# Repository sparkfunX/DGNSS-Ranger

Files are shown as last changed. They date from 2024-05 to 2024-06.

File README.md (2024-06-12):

# DGNSS_Ranger
Shoulder-Mounted Collapsable LIDAR-DGNSS Rangefinder/Locator Development Platform

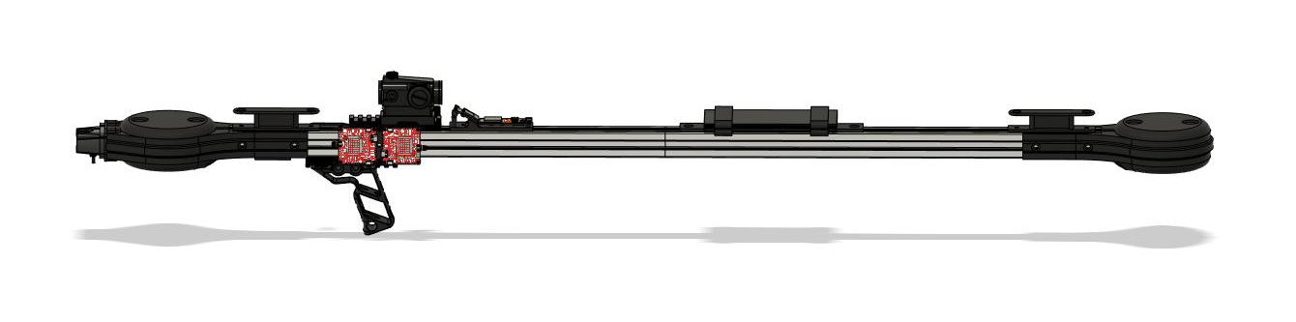
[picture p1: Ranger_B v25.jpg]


## Theory of Operation 
By using two GNSS receivers operating in RTK with corrections data from a fixed base (or comparable corrections source) the relative position of two antennas can be determined. This relative position can be used to derive a heading without the use of a magnetic compass. Furthermore, by placing a ranging sensor (in this case, a LIDAR) in line with these antennas, it's possible to derive the Geodetic coordinates of a subject at distance. This is acheived by virtually extending a line that connects the two antennas by the distance reported by the LIDAR. This may be useful in applications such as surveying, geotagging, structural measurments, etc. where it's neccessary to retrieve the coordinates of an inaccessible subject. The shoulder-mounted form factor of this platform makes it easier to use and transport than many traditional surveying tools, at the expense of some positional accuracy. 

## Sources of Error
We've determined the theoretical maximum 3D positional error of the platform at full distance (40 meters) to be 0.85 meters. This error is the result of compounding error from various sources.

#### GNSS Error
The maximum 3D accuracy of the ZED-F9P with a clear view of the sky and adequate corrections data is 0.02 meters. This error is inherent to the method and can't be technically addressed by this project.

#### Differential Error at Distance 
Assuming the maximum 3D positional error of the forward antenna is 0.02m, and that its distance from the rear antenna is 0.95m, we derive an angular error of 1.206° (The α angle of the right triangle with b side 0.95 and a side 0.02) such that at 40 meters, the maximum positional error becomes 0.85 meters (The a side of the right triangle with α angle 1.206° and b side 40). This error can be reduced by increasing the length of the platform and, therefore, the distance between the two GNSS antennas. This is because the angular error is reduced with an increased distance given the same positional error (Observe the difference in angle between a right triangle with b side 0.95 and a side 0.02 and another right triangle with b side 2 and a side 0.02). The distance between the two antenna does not need to be calibrated, as it is measured using DGNSS, and so it is possible to extend the platform's length as much as is practical in a given application without modifying the firmware. This error also shrinks with the distance to the subject and so more accurate coordinates are derived from nearer subjects. Note: The inter-antenna distance is automatically derived via DGNSS, but the distance between the LIDAR unit and the forward antenna ARP should remain fixed and must be accounted for in the firmware configuration. 

#### LIDAR Ranging Error
The accuracy of any LIDAR rangefinder will depend on a number of environmental factors, including the cross-sectional area and reflectivity of the subject to be measured. For this reason, ranging errors are not included in our maximum error figure. 

## Electrical Assembly
Almost all of the electronics on the platform are SparkFun Qwiic development boards and can be connected using Qwiic cables in whatever order is most mechanically convenient. The only exceptions are the trigger button and the LIDAR-lite module. The trigger button is simply wired between Pin 13 and GND on the Thing Plus development board. The LIDAR-lite is wired to the Qwiic Boost board. Be careful to connect the forward and rear ZED-F9P breakouts to their respective antennas. The platform can be powered from any 5V power source using the USB-C connector on the Thing Plus development board. 

## Bill of Materials
The full bill of materials for this project can be found [here](https://github.com/sparkfunX/DGNSS_Ranger/blob/main/DGNSS%20Ranger%20BOM.pdf). Most, if not all, of the mechanical parts can be substituted with a suitable equivalent. The grip, for instance, can be substituted with any accessory-rail-mounted foregrip. The platform is built using two pieces of aluminum extrusion which are connected end-to-end so that it can be dismantled for travel, but a single piece of extrusion will also work. The length of the extrusion is not critical, and the platform will become more accurate the longer it is (see "Differential Error at Distance"). All of the 3D printed parts for the platform can be found in this repository and are linked from their respective rows in the BOM. The parts used in our prototype were all printed on a Creality CR-10 FDM printer using PLA filament. 

## Firmware
The firmware as provided here is INCOMPLETE. It can currently initialize the platform and generate example measurements using a fixed distance measurement, some small work needs to be done to retrieve real distance information from the LIDAR unit. The user interface is extremely minimal, with debug information being provided over a serial connection. 

## Provided As-Is
This platform is a work in progress and should not be considered a complete, or even functioning, measurement platform. 

Repository Contents
-------------------

* **/Firmware** - Arduino Code
* **/Mechanical** - Fusion 360 design archive, STL models, and drawings

License Information
-------------------

This project is _**open source**_! 

Please review the LICENSE.md file for license information. 

If you have any questions or concerns on licensing, please contact technical support on our [SparkFun forums](https://forum.sparkfun.com/viewforum.php?f=152).

Distributed as-is; no warranty is given.

- Your friends at SparkFun.

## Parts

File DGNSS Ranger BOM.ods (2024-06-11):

Part Name | Qty | Source Link
Structure
Aluminum Extrusion 30mm x 30mm with 8mm T-Slot Cut to Length 600mm | 2 | https://a.co/d/hFK5Cv9
Straight Connector Joint with M6 Screws for 8mm T Slot (4 pcs) | 1 | https://a.co/d/0ECLUNQ
Mounting Hardware
3030 Series 50-Pack M5 T-Nuts | 1 | https://a.co/d/2LNsleN
M5 Hex Socket Cap Machine Screws Assortment | 1 | https://a.co/d/iCjtODC
M5 Flat Head Socket Cap Screws Assortment | 1 | https://a.co/d/0aGesk0
Picatinny Accessory Rail Set | 1 | https://a.co/d/frnKe9S
Electronics
SparkFun GPS-RTK-SMA Breakout - ZED-F9P (Qwiic) | 2 | https://www.sparkfun.com/products/16481
SparkFun Thing Plus - ESP32-S2 WROOM | 1 | https://www.sparkfun.com/products/17743
SparkFun Micro OLED Breakout (Qwiic) | 1 | https://www.sparkfun.com/products/22495
Qwiic Boost | 1 | https://www.sparkfun.com/products/17238
LIDAR-Lite v3HP | 1 | https://www.sparkfun.com/products/14599
SparkFun Qwiic Cable Kit | 1 | https://www.sparkfun.com/products/15081
Cherry MX Switch | 1 | https://www.sparkfun.com/products/13834
Cherry MX Keycap | 1 | https://www.sparkfun.com/products/15305
GNSS L1/L2 Multi-Band Magnetic Mount Antenna | 2 | https://www.sparkfun.com/products/15192
GPS Antenna Ground Plate | 2 | https://www.sparkfun.com/products/17519
Misc
Red Dot Sight with 1 inch Riser Mount | 1 | https://a.co/d/gIp6rdF
3D Printed Components
Forward Antenna Pod | 1 | https://github.com/sparkfunX/DGNSS_Ranger/blob/main/Mechanical/STL/Forward%20Pod.stl
Rear Antenna Pod | 1 | https://github.com/sparkfunX/DGNSS_Ranger/blob/main/Mechanical/STL/Rear%20Pod.stl
Antenna Pod Lid | 2 | https://github.com/sparkfunX/DGNSS_Ranger/blob/main/Mechanical/STL/Pod%20Lid.stl
Antenna Cable Spool | 2 | https://github.com/sparkfunX/DGNSS_Ranger/blob/main/Mechanical/STL/Cable%20Spool.stl
Grip | 1 | https://github.com/sparkfunX/DGNSS_Ranger/blob/main/Mechanical/STL/Grip.stl
Qwiic Boost Mounting Plate | 1 | https://github.com/sparkfunX/DGNSS_Ranger/blob/main/Mechanical/STL/Qwiic%20Boost%20Mount.stl
Dual ZED-F9P Mounting Plate | 1 | https://github.com/sparkfunX/DGNSS_Ranger/blob/main/Mechanical/STL/F9P%20Mount.stl
OLED+ThingPlus Mounting Plate | 1 | https://github.com/sparkfunX/DGNSS_Ranger/blob/main/Mechanical/STL/OLED%20Mount.stl
Trigger Button Assembly | 1 | https://github.com/sparkfunX/DGNSS_Ranger/blob/main/Mechanical/STL/Trigger%20Mount.stl

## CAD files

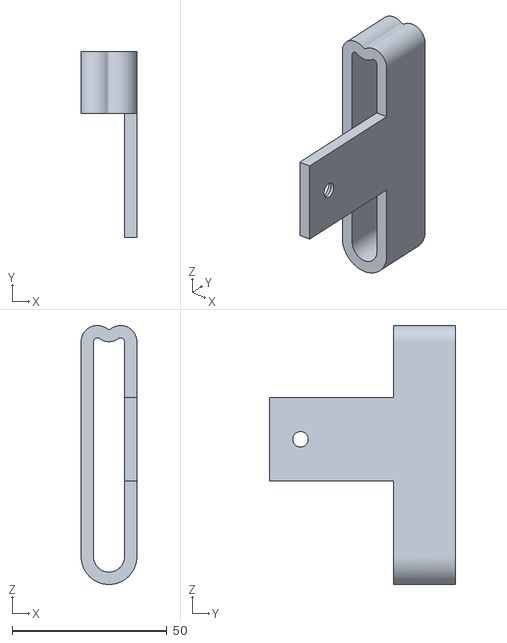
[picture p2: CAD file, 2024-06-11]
Mechanical/STL/Battery Pack Mount.stl
18.0 x 60.0 x 83.5

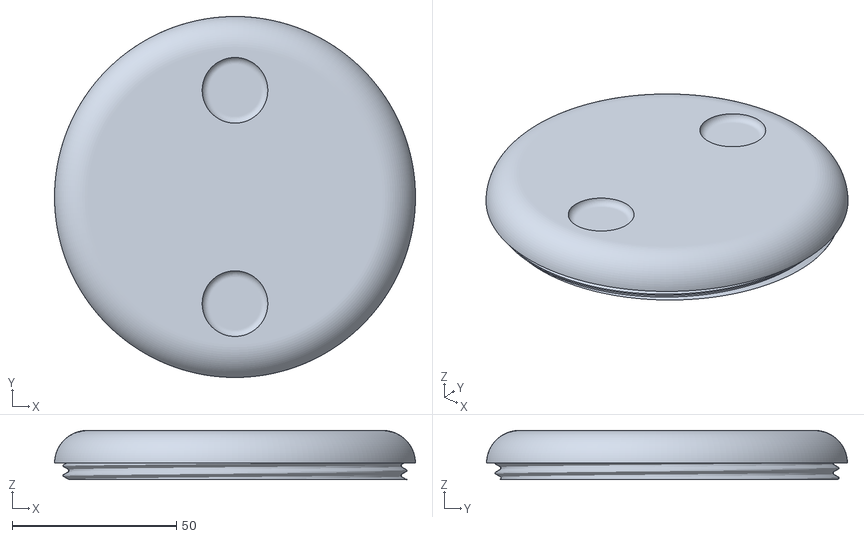
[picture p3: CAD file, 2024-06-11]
Mechanical/STL/Pod Lid.stl
110.0 x 110.0 x 15.0

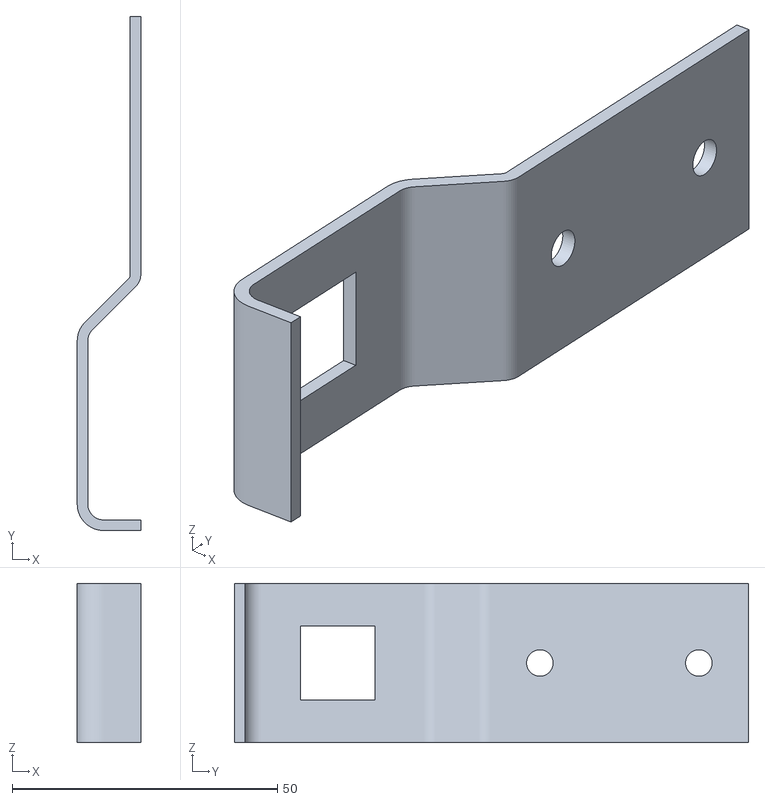
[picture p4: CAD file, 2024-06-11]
Mechanical/STL/Trigger Mount.stl
12.0 x 97.0 x 30.0

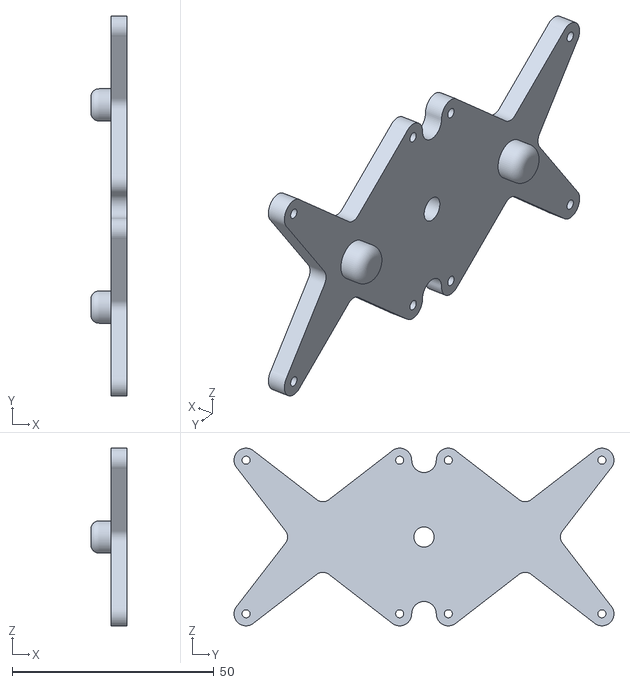
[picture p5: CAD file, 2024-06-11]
Mechanical/STL/F9P Mount.stl
9.00 x 94.3 x 44.1

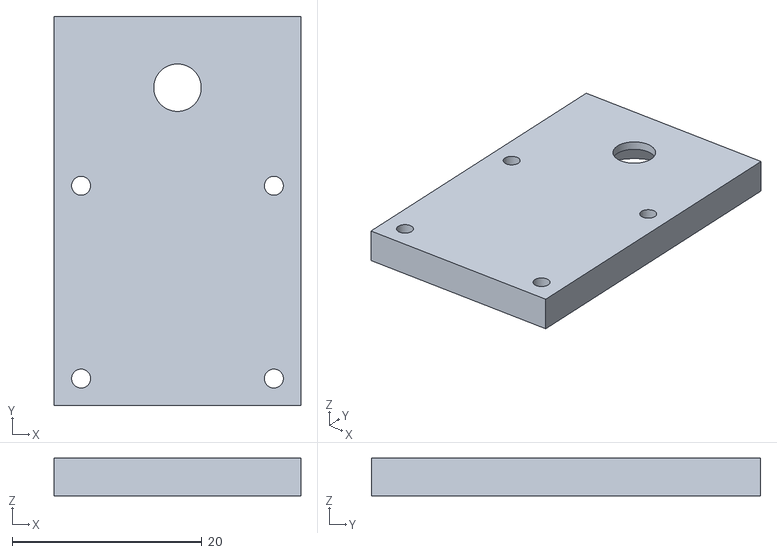
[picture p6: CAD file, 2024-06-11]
Mechanical/STL/Qwiic Boost Mount.stl
26.0 x 41.0 x 4.00

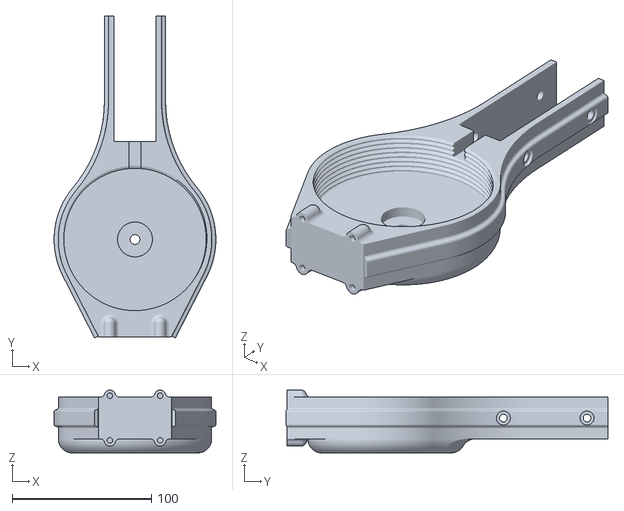
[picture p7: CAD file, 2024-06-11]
Mechanical/STL/Forward Pod.stl
116.0 x 230.8 x 45.1

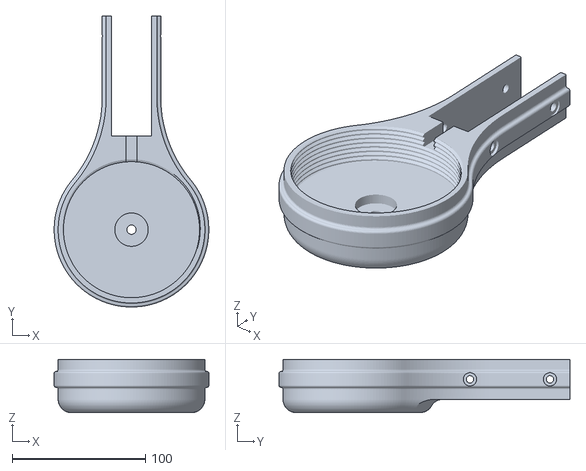
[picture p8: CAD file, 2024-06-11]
Mechanical/STL/Rear Pod.stl
116.0 x 218.2 x 40.0

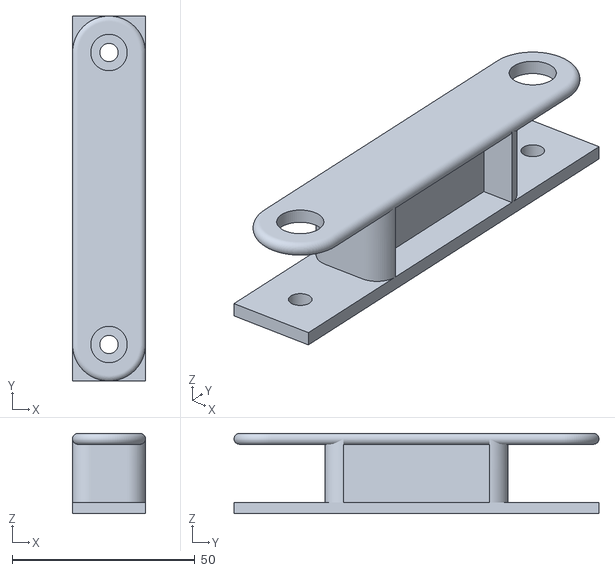
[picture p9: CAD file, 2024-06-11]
Mechanical/STL/Cable Spool.stl
20.0 x 100.0 x 22.0

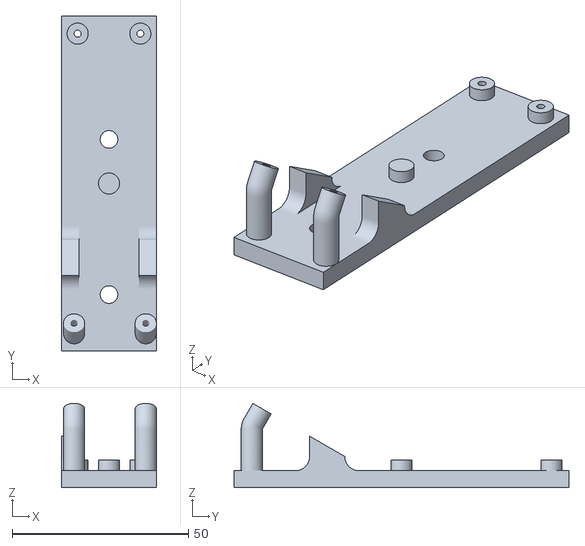
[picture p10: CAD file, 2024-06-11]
Mechanical/STL/OLED Mount.stl
27.0 x 95.0 x 23.9

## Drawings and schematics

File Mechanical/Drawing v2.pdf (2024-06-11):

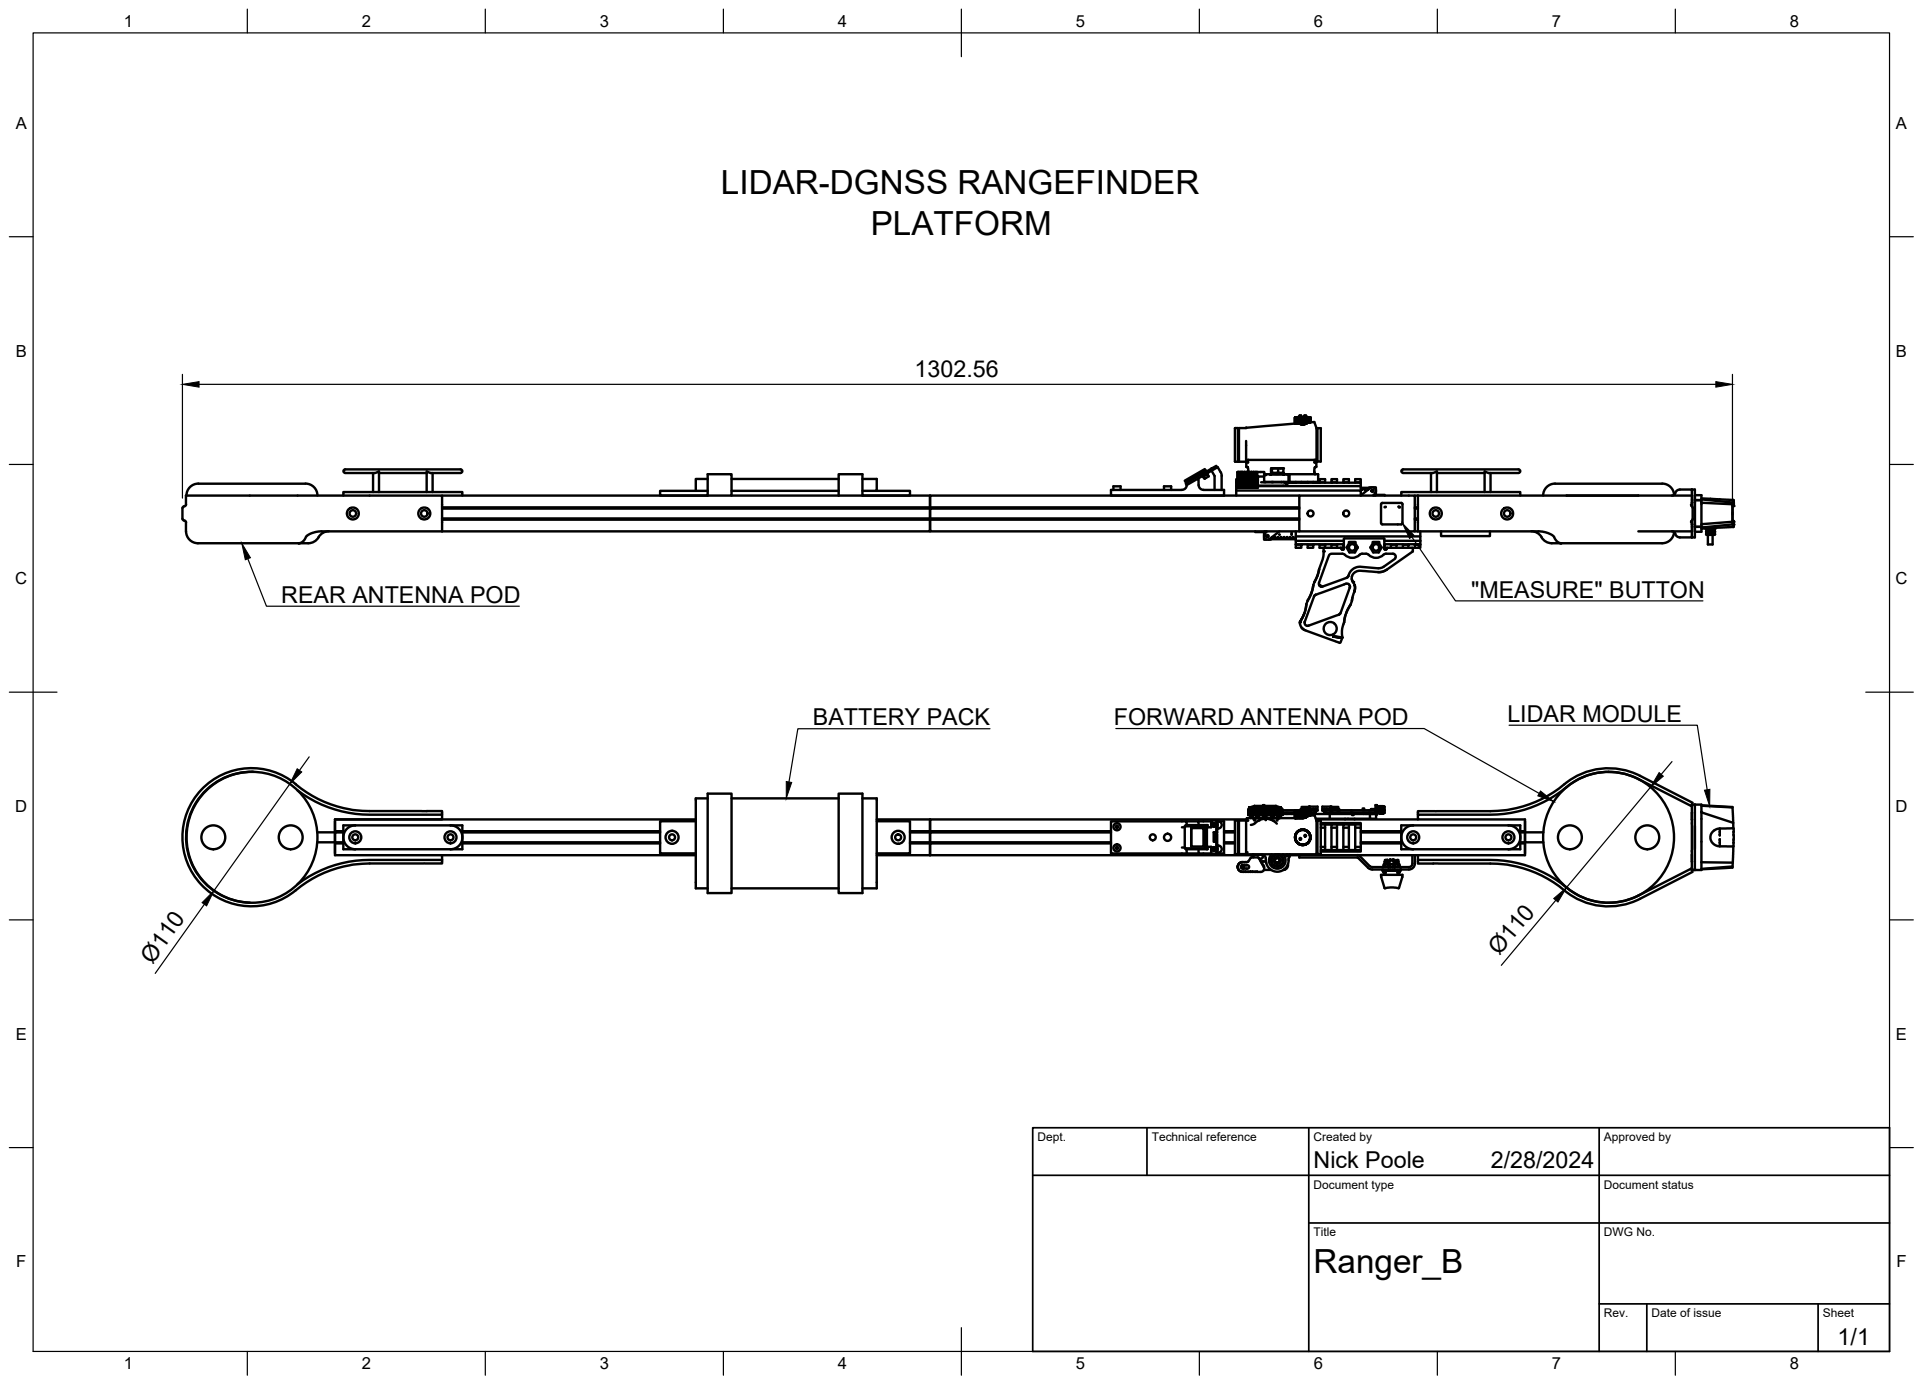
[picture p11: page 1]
Dept.; Technical reference; Created by; Approved by; Document type; Document status; Title; DWG No.; Rev.; Date of issue; Sheet; Nick Poole; "MEASURE" BUTTON; LIDAR MODULE; BATTERY PACK; FORWARD ANTENNA POD

LIDAR-DGNSS RANGEFINDER

REAR ANTENNA POD

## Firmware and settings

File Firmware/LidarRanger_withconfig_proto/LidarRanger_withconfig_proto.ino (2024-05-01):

#include <WiFi.h>
#include "secrets.h"

#include <Wire.h> // Needed for I2C to GNSS

#include <SparkFun_u-blox_GNSS_v3.h> // http://librarymanager/All#SparkFun_u-blox_GNSS_v3
SFE_UBLOX_GNSS GNSS_Forward;
SFE_UBLOX_GNSS GNSS_Rear;

#include <SparkFun_Qwiic_OLED.h> // http://librarymanager/All#SparkFun_Qwiic_OLED
QwiicMicroOLED myOLED;

// The ESP32 core has a built in base64 library but not every platform does
// We'll use an external lib if necessary.
#if defined(ARDUINO_ARCH_ESP32)
#include "base64.h" // Built-in ESP32 library
#else
#include <Base64.h> // nfriendly library from https://github.com/adamvr/arduino-base64, will work with any platform
#endif

#define triggerButton 13

long lastReceivedRTCM_ms = 0; // 5 RTCM messages take approximately ~300ms to arrive at 115200bps
int maxTimeBeforeHangup_ms = 20000; // If we fail to get a complete RTCM frame after 10s, then disconnect from caster
double RELPOSN = 0;
double RELPOSE = 0;
double RELPOSD = 0; 
double LAT = 0;
double LON = 0;
double ALT = 0;

const double degreesToRadians = PI/180; 
const double radiansToDegrees = 180/PI; 
const double WGS84_A = 6378137;           // https://geographiclib.sourceforge.io/html/Constants_8hpp_source.html
const double WGS84_E = 0.081819190842622; // http://docs.ros.org/en/hydro/api/gps_common/html/namespacegps__common.html
                                          // and https://gist.github.com/uhho/63750c4b54c7f90f37f958cc8af0c718

// The following come from https://gist.github.com/govert/1b373696c9a27ff4c72a                                          
const double WGS84_B = 6356752.314245;                  // Derived Earth semiminor axis (m)
const double WGS84_F = (WGS84_A - WGS84_B) / WGS84_A;   // Ellipsoid Flatness
const double WGS84_F_inv = 1.0 / WGS84_F;               // Inverse flattening

const double WGS84_A_sq = WGS84_A * WGS84_A;
const double WGS84_B_sq = WGS84_B * WGS84_B;
const double WGS84_E_sq = WGS84_F * (2 - WGS84_F);      // Square of Eccentricity


void setup() 
{

  Serial.begin(115200); // Start UART for debug/config

  // 5 seconds on startup to enter the ublox module config
  while (Serial.available()) Serial.read(); // Trash any incoming chars
  Serial.println(F("Press Any Key to run u-blox config"));
  for (int d = 0; d < 5; d++)
  {
    if(Serial.available()) ubloxConfig();
    delay(1000);
  }

  Serial.println(F("u-blox config skipped"));

  // Start I2C
  Wire.begin();
  delay(50);
  Wire.setClock(400000);

  // Initalize the OLED device and related graphics system
  if (myOLED.begin() == false)
  {
      Serial.println("OLED begin failed. Freezing...");
      while(1);
  }

  printOLED(String("u-blox wait"));

  // Connect to rear (moving base) u-blox module
  if (GNSS_Rear.begin(Wire, 0x3F) == false)
  {
    printOLED(String("u-blox error"));
    Serial.println(F("Rear GNSS module not detected at 0x3F. Please check wiring and configuration. Freezing."));
    while(1);
  }

  // Connect to forward (rover) u-blox module
  if (GNSS_Forward.begin() == false)
  {
    printOLED(String("u-blox error"));
    Serial.println(F("Forward GNSS module not detected at 0x42. Please check wiring and configuration. Freezing."));
    while(1);
  }  

  GNSS_Rear.setI2COutput(COM_TYPE_UBX); //Turn off NMEA noise
  GNSS_Rear.setI2CInput(COM_TYPE_UBX | COM_TYPE_NMEA | COM_TYPE_RTCM3); //Be sure RTCM3 input is enabled. UBX + RTCM3 is not a valid state.

  GNSS_Forward.setAutoRELPOSNEDcallbackPtr(&updateRELPOSNED); // Enable automatic NAV RELPOSNED messages with callback to updateRELPOSNED
  
  printOLED("u-blox OK");

  delay(1000);

  // Start WiFi for NTRIP 
  printOLED("wait for WiFi");
  WiFi.begin(ssid, password);
  while (WiFi.status() != WL_CONNECTED) {
    delay(500);
    Serial.print(F("."));
  }
  Serial.println();

  printOLED("WiFi OK");
  delay(3000);
  //printOLED(String(WiFi.localIP()));  

  // Set pinMode for trigger input
  pinMode(triggerButton, INPUT_PULLUP);  

  // Trash any incoming chars
  while (Serial.available()) Serial.read();

}

//------------------------------------------
// Main Loop
// This is just a place to wait for user input 
// and a place to return when NTRIP times out
//------------------------------------------
void loop() 
{
    
  printOLED("Start?");
  while(digitalRead(triggerButton) == 1){};
  beginClient();

}

//------------------------------------------
// beginClient()
// Connect to NTRIP Caster, receive RTCM, 
// and push to rear ublox module over I2C.
// Check forward ublox module for updated
// relative positioning information.
//------------------------------------------
void beginClient()
{
  WiFiClient ntripClient;
  long rtcmCount = 0;

  Serial.println(F("Subscribing to Caster. Press key to stop"));
  delay(10); //Wait for any serial to arrive
  while (Serial.available()) Serial.read(); //Flush

  while (Serial.available() == 0)
  {
    // Connect if we are not already. Limit to 5s between attempts.
    if (ntripClient.connected() == false)
    {
      Serial.print(F("Opening socket to "));
      Serial.println(casterHost);

      if (ntripClient.connect(casterHost, casterPort) == false) // Attempt connection
      {
        Serial.println(F("Connection to caster failed"));
        return;
      }
      else
      {
        Serial.print(F("Connected to "));
        Serial.print(casterHost);
        Serial.print(F(": "));
        Serial.println(casterPort);

        Serial.print(F("Requesting NTRIP Data from mount point "));
        Serial.println(mountPoint);

        const int SERVER_BUFFER_SIZE  = 512;
        char serverRequest[SERVER_BUFFER_SIZE];

        snprintf(serverRequest, SERVER_BUFFER_SIZE, "GET /%s HTTP/1.0\r\nUser-Agent: NTRIP SparkFun u-blox Client v1.0\r\n",
                 mountPoint);

        char credentials[512];
        if (strlen(casterUser) == 0)
        {
          strncpy(credentials, "Accept: */*\r\nConnection: close\r\n", sizeof(credentials));
        }
        else
        {
          //Pass base64 encoded user:pw
          char userCredentials[sizeof(casterUser) + sizeof(casterUserPW) + 1]; //The ':' takes up a spot
          snprintf(userCredentials, sizeof(userCredentials), "%s:%s", casterUser, casterUserPW);

          Serial.print(F("Sending credentials: "));
          Serial.println(userCredentials);

#if defined(ARDUINO_ARCH_ESP32)
          //Encode with ESP32 built-in library
          base64 b;
          String strEncodedCredentials = b.encode(userCredentials);
          char encodedCredentials[strEncodedCredentials.length() + 1];
          strEncodedCredentials.toCharArray(encodedCredentials, sizeof(encodedCredentials)); //Convert String to char array
          snprintf(credentials, sizeof(credentials), "Authorization: Basic %s\r\n", encodedCredentials);
#else
          //Encode with nfriendly library
          int encodedLen = base64_enc_len(strlen(userCredentials));
          char encodedCredentials[encodedLen]; //Create array large enough to house encoded data
          base64_encode(encodedCredentials, userCredentials, strlen(userCredentials)); //Note: Input array is consumed
#endif
        }
        strncat(serverRequest, credentials, SERVER_BUFFER_SIZE);
        strncat(serverRequest, "\r\n", SERVER_BUFFER_SIZE);

        Serial.print(F("serverRequest size: "));
        Serial.print(strlen(serverRequest));
        Serial.print(F(" of "));
        Serial.print(sizeof(serverRequest));
        Serial.println(F(" bytes available"));

        Serial.println(F("Sending server request:"));
        Serial.println(serverRequest);
        ntripClient.write(serverRequest, strlen(serverRequest));

        //Wait for response
        unsigned long timeout = millis();
        while (ntripClient.available() == 0)
        {
          if (millis() - timeout > 5000)
          {
            Serial.println(F("Caster timed out!"));
            ntripClient.stop();
            return;
          }
          delay(10);
        }

        // Check reply
        bool connectionSuccess = false;
        char response[512];
        int responseSpot = 0;
        while (ntripClient.available())
        {
          if (responseSpot == sizeof(response) - 1) break;

          response[responseSpot++] = ntripClient.read();
          if (strstr(response, "200") > 0) // Look for 'ICY 200 OK'
            connectionSuccess = true;
          if (strstr(response, "401") > 0) // Look for '401 Unauthorized'
          {
            Serial.println(F("Hey - your credentials look bad! Check you caster username and password."));
            connectionSuccess = false;
          }
        }
        response[responseSpot] = '\0';

        Serial.print(F("Caster responded with: "));
        Serial.println(response);

        if (connectionSuccess == false)
        {
          Serial.print(F("Failed to connect to "));
          Serial.print(casterHost);
          Serial.print(F(": "));
          Serial.println(response);
          return;
        }
        else
        {
          Serial.print(F("Connected to "));
          Serial.println(casterHost);
          lastReceivedRTCM_ms = millis(); // Reset timeout
        }
      } //End attempt to connect
    } //End connected == false

    if (ntripClient.connected() == true)
    {
      // Check if user is pressing the trigger
      if(digitalRead(triggerButton) == 0)
      { 
        delay(500);
        makeMeasurement();
      }
      
      uint8_t rtcmData[512 * 4]; // Most incoming data is around 500 bytes but may be larger
      rtcmCount = 0;

      //Print any available RTCM data
      while (ntripClient.available())
      {
        //Serial.write(ntripClient.read()); // Pipe to serial port is fine but beware, it's a lot of binary data
        rtcmData[rtcmCount++] = ntripClient.read();
        if (rtcmCount == sizeof(rtcmData)) break;
      }

      if (rtcmCount > 0)
      {
        lastReceivedRTCM_ms = millis();

        // Push RTCM to rear ublox module over I2C
        GNSS_Rear.pushRawData(rtcmData, rtcmCount, false);
        Serial.print(F("RTCM pushed to ZED: "));
        Serial.println(rtcmCount);

        // Check for new RELPOSNED data
        GNSS_Forward.checkUblox(); 
        GNSS_Forward.checkCallbacks();

        // Check for new HPPOS data
        if (GNSS_Rear.getHPPOSLLH())
        {
          checkHPPos();
        }
      }
    }

    // Close socket if we don't have new data for 10s
    if (millis() - lastReceivedRTCM_ms > maxTimeBeforeHangup_ms)
    {
      Serial.println(F("RTCM timeout. Disconnecting..."));
      if (ntripClient.connected() == true)
        ntripClient.stop();
      return;
    }

    delay(10);
  }

  Serial.println(F("User pressed a key"));
  Serial.println(F("Disconnecting..."));
  ntripClient.stop();
}

//------------------------------------------
// ubloxConfig()
// Reset ublox modules to factory settings and 
// then load the correct configuration for 
// moving base operation.
// Because the ublox modules will have the same 
// I2C address by default, we require the technician
// to unplug everything after the first module 
// for part of this configuration routine
//------------------------------------------
void ubloxConfig()
{
  while (Serial.available()) Serial.read(); // Trash any incoming chars
  Serial.println(F("Connect ONLY the rear u-blox module to the Qwiic Bus and press any key"));
  while (Serial.available() == false) ; // Wait for user to send character

  Wire.begin();
  Wire.setClock(400000); // Increase I2C clock speed to 400kHz
  delay(50);

  if (GNSS_Rear.begin() == false) // Connect to the u-blox module using Wire port
  {
    Serial.println(F("u-blox GNSS not detected at default I2C address. Checking second address."));
    if (GNSS_Rear.begin(Wire, 0x3F) == false) // Connect to the u-blox module using Wire port
    {
      Serial.println(F("u-blox GNSS not detected at either expected address. Please check wiring. Freezing."));
      while(1);
    }      
  }  

  Serial.println(F("Restoring rear module to clean configuration (factory reset) please wait..."));

  GNSS_Rear.factoryDefault(); // Reset everything: baud rate, I2C address, update rate, everything.

  delay(5000); // Wait while the module restarts

  while (GNSS_Rear.begin() == false) //Attempt to re-connect
  {
    delay(1000);
    Serial.print(F("Attempting to re-connect to rear module after reset... "));
  }

  Serial.println(F(" Success."));
  Serial.print(F("Attempting to change rear module address"));

  GNSS_Rear.setI2CAddress(0x3F, VAL_LAYER_RAM_BBR);

  delay(2000); // Allow time for the change to take

  GNSS_Rear.end();

  while (GNSS_Rear.begin(Wire, 0x3F) == false) // Attempt to re-connect
  {
    delay(1000);
    Serial.print(F("Attempting to re-connect to rear module at new address... "));
  }  

  Serial.println(F(" Success."));
  Serial.println(F("Configuring rear module for Moving Base Operation. Please wait..."));

  bool setValueSuccess = true;

  //------------------------------------------
  // MOVING BASE CONFIGURATION
  //------------------------------------------

  //Begin with newCfgValset
  setValueSuccess = GNSS_Rear.newCfgValset(); // Defaults to configuring the setting in RAM and BBR

  // Add KeyIDs and Values
  setValueSuccess &= GNSS_Rear.addCfgValset(UBLOX_CFG_UART2INPROT_NMEA, 0); 
  setValueSuccess &= GNSS_Rear.addCfgValset(UBLOX_CFG_UART2INPROT_RTCM3X, 0); 
  setValueSuccess &= GNSS_Rear.addCfgValset(UBLOX_CFG_UART2INPROT_UBX, 0); 
  setValueSuccess &= GNSS_Rear.addCfgValset(UBLOX_CFG_UART2OUTPROT_NMEA, 0); 
  setValueSuccess &= GNSS_Rear.addCfgValset(UBLOX_CFG_UART2OUTPROT_RTCM3X, 1); 
  setValueSuccess &= GNSS_Rear.addCfgValset(UBLOX_CFG_UART2OUTPROT_UBX, 0); 

  setValueSuccess &= GNSS_Rear.addCfgValset(UBLOX_CFG_I2CINPROT_RTCM3X, 1); 
  setValueSuccess &= GNSS_Rear.addCfgValset(UBLOX_CFG_I2COUTPROT_UBX, 1); 
  
  setValueSuccess &= GNSS_Rear.addCfgValset(UBLOX_CFG_MSGOUT_RTCM_3X_TYPE4072_0_UART2, 1); 
  setValueSuccess &= GNSS_Rear.addCfgValset(UBLOX_CFG_MSGOUT_RTCM_3X_TYPE1077_UART2, 1); 
  setValueSuccess &= GNSS_Rear.addCfgValset(UBLOX_CFG_MSGOUT_RTCM_3X_TYPE1087_UART2, 1); 
  setValueSuccess &= GNSS_Rear.addCfgValset(UBLOX_CFG_MSGOUT_RTCM_3X_TYPE1097_UART2, 1); 
  setValueSuccess &= GNSS_Rear.addCfgValset(UBLOX_CFG_MSGOUT_RTCM_3X_TYPE1127_UART2, 1); 
  setValueSuccess &= GNSS_Rear.addCfgValset(UBLOX_CFG_MSGOUT_RTCM_3X_TYPE1230_UART2, 1); 

  setValueSuccess &= GNSS_Rear.addCfgValset(UBLOX_CFG_MSGOUT_RTCM_3X_TYPE4072_0_USB, 1); 
  setValueSuccess &= GNSS_Rear.addCfgValset(UBLOX_CFG_MSGOUT_RTCM_3X_TYPE1077_USB, 1); 
  setValueSuccess &= GNSS_Rear.addCfgValset(UBLOX_CFG_MSGOUT_RTCM_3X_TYPE1087_USB, 1); 
  setValueSuccess &= GNSS_Rear.addCfgValset(UBLOX_CFG_MSGOUT_RTCM_3X_TYPE1097_USB, 1); 
  setValueSuccess &= GNSS_Rear.addCfgValset(UBLOX_CFG_MSGOUT_RTCM_3X_TYPE1127_USB, 1); 
  setValueSuccess &= GNSS_Rear.addCfgValset(UBLOX_CFG_MSGOUT_RTCM_3X_TYPE1230_USB, 1); 

  setValueSuccess &= GNSS_Rear.addCfgValset(UBLOX_CFG_MSGOUT_UBX_NAV_PVT_USB, 1); 
  setValueSuccess &= GNSS_Rear.addCfgValset(UBLOX_CFG_MSGOUT_UBX_NAV_SVIN_USB, 1); 
  setValueSuccess &= GNSS_Rear.addCfgValset(UBLOX_CFG_UART2_BAUDRATE, 460800); 

  // Send the packet using sendCfgValset
  setValueSuccess &= GNSS_Rear.sendCfgValset();

  if (setValueSuccess == true)
  {
    Serial.println("Moving Base Config successfully set");
  }
  else
  {
    Serial.println("Moving Base Config set failed. freezing");  
    while(1);
  }

  Serial.println(F("Ending connection with rear module"));
  GNSS_Rear.end();
  Wire.end();  

  while (Serial.available()) Serial.read(); // Trash any incoming chars
  Serial.println(F("Connect the forward u-blox module and the remainder of the Qwiic Bus and press any key"));
  while (Serial.available() == false) ; // Wait for user to send character

  Wire.begin();
  Wire.setClock(400000); // Increase I2C clock speed to 400kHz
  delay(50);

  if (GNSS_Forward.begin() == false) // Connect to the u-blox module using Wire port
  {
    Serial.println(F("u-blox GNSS not detected at default I2C address. Please check wiring. Freezing."));
    while (1);
  }  

  Serial.println(F("Restoring forward module to clean configuration (factory reset) please wait..."));

  GNSS_Forward.factoryDefault(); // Reset everything: baud rate, I2C address, update rate, everything.

  delay(5000); // Wait while the module restarts

  while (GNSS_Forward.begin() == false) // Attempt to re-connect
  {
    delay(1000);
    Serial.print(F("Attempting to re-connect to forward module after reset... "));
  }

  Serial.print(F("Success."));
  Serial.println(F("Configuring forward module for Rover Operation. Please wait..."));

  setValueSuccess = true;

  //------------------------------------------
  // ROVER CONFIGURATION
  //------------------------------------------

  // Begin with newCfgValset
  setValueSuccess = GNSS_Forward.newCfgValset(); // Defaults to configuring the setting in RAM and BBR

  // Add KeyIDs and Values
  setValueSuccess &= GNSS_Forward.addCfgValset(UBLOX_CFG_UART2INPROT_NMEA, 0); 
  setValueSuccess &= GNSS_Forward.addCfgValset(UBLOX_CFG_UART2INPROT_RTCM3X, 1); 
  setValueSuccess &= GNSS_Forward.addCfgValset(UBLOX_CFG_UART2INPROT_UBX, 0); 
  setValueSuccess &= GNSS_Forward.addCfgValset(UBLOX_CFG_UART2OUTPROT_NMEA, 0); 
  setValueSuccess &= GNSS_Forward.addCfgValset(UBLOX_CFG_UART2OUTPROT_RTCM3X, 0); 
  setValueSuccess &= GNSS_Forward.addCfgValset(UBLOX_CFG_UART2OUTPROT_UBX, 0); 

  setValueSuccess &= GNSS_Forward.addCfgValset(UBLOX_CFG_MSGOUT_UBX_NAV_RELPOSNED_I2C, 1); 
  setValueSuccess &= GNSS_Forward.addCfgValset(UBLOX_CFG_MSGOUT_UBX_NAV_RELPOSNED_USB, 0);   
  
  setValueSuccess &= GNSS_Forward.addCfgValset(UBLOX_CFG_USBINPROT_NMEA, 1); 
  setValueSuccess &= GNSS_Forward.addCfgValset(UBLOX_CFG_USBINPROT_RTCM3X, 1); 
  setValueSuccess &= GNSS_Forward.addCfgValset(UBLOX_CFG_USBINPROT_UBX, 1); 
  setValueSuccess &= GNSS_Forward.addCfgValset(UBLOX_CFG_USBOUTPROT_NMEA, 1); 
  setValueSuccess &= GNSS_Forward.addCfgValset(UBLOX_CFG_USBOUTPROT_RTCM3X, 0); 
  setValueSuccess &= GNSS_Forward.addCfgValset(UBLOX_CFG_USBOUTPROT_UBX, 1);   

  setValueSuccess &= GNSS_Forward.addCfgValset(UBLOX_CFG_UART2_BAUDRATE, 460800); 

  // Send the packet using sendCfgValset
  setValueSuccess &= GNSS_Forward.sendCfgValset();

  if (setValueSuccess == true)
  {
    Serial.println("Rover Config successfully set");
  }
  else
  {
    Serial.println("Rover Config set failed. freezing");  
    while(1);
  } 

  Serial.println(F("Ending connection with forward module"));
  GNSS_Forward.end();
  Wire.end();  

  Serial.println(F("Configuration successful"));

  return;
}

//------------------------------------------
// printOLED(String)
// Just a simple helper function that takes
// a String and prints it to the center of
// the OLED module
//------------------------------------------
void printOLED(String outString)
{
  myOLED.erase();

  // starting x position - screen width minus string width  / 2
  int x0 = (myOLED.getWidth() - myOLED.getStringWidth(outString)) / 2;

  // starting y position - screen height minus string height / 2 
  int y0 = (myOLED.getHeight() - myOLED.getStringHeight(outString)) / 2;

  // Draw the text - color of black (0)
  myOLED.text(x0, y0, outString, 4);

  // There's nothing on the screen yet - Now send the graphics to the device
  myOLED.display();
}

//------------------------------------------
// updateRELPOSNED(UBX_NAV_RELPOSNED_data_t)
// Callback to retreive and populate the 
// relative position data from the forward 
// ublox module
//------------------------------------------
void updateRELPOSNED(UBX_NAV_RELPOSNED_data_t *ubxDataStruct)
{
  Serial.println("Fresh RELPOS");
  RELPOSN = ((double)ubxDataStruct->relPosN / 100) + ((double)ubxDataStruct->relPosHPN / 10000);
  RELPOSE = ((double)ubxDataStruct->relPosE / 100) + ((double)ubxDataStruct->relPosHPE / 10000);
  RELPOSD = ((double)ubxDataStruct->relPosD / 100) + ((double)ubxDataStruct->relPosHPD / 10000);
}
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

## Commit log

2024-06-11 Add STLs and Fusion Archive
    [Battery Pack Mount.stl, Cable Spool.stl, F9P Mount.stl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]
2024-06-11 Add BOM
    [DGNSS Ranger BOM.ods]
